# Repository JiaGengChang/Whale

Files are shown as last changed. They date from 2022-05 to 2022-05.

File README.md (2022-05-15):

# Whale Pro Micro

**Whale** is drop-in USB-C replacement for the sparkfun Pro Micro popular in split keyboards. It is a modified version of **[Goldfish]** by staticintlucas that uses a cheaply available USB-C receptacle. In Mandarin, goldfish sounds the same as whale.

Link to [Schematics]
Link to [PCB gerber files]

---

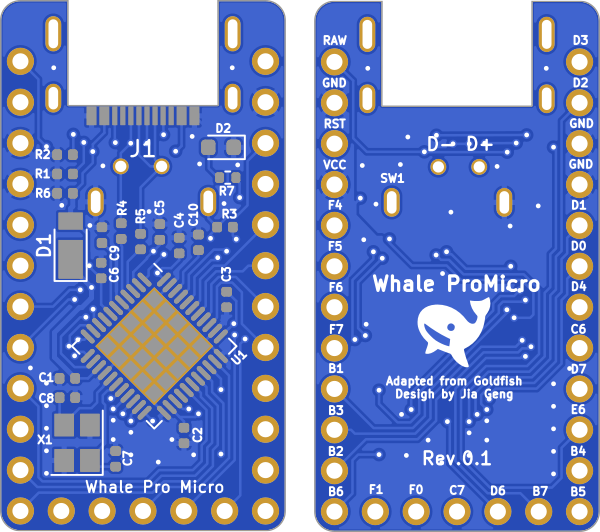
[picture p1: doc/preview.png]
Preview


---

## Modifications to Goldfish

- PCB designed to fit cheap USB-C connector available on aliexpress **[usb-c-link]**.
- Reset switch that can be soldered on the back of the board (6mm by 2.5mm switch)**[switch-link]**.
- Different silkscreen text and art
- LED for power-source
---

## Disadvantages compared to other Goldfish-based boards

- Unlike **[Alvaro]**, it does not incorporate a fuse
- It also uses 0402 form factor capacitors and resistors, which is difficult to solder by hand
- No working boards tested!! (verdict will be out soon, watch this space)
---

## License

**[Creative Commons Attribution Share-Alike 4.0 License][License]**.

**-** Original `Arduino Mini` design by **Team Arduino**.

**-** Arduino `Pro Mini` design by **Spark Fun Electronics**.

**-** `Pro Micro` design by **Spark Fun Electronics**.

**-** Wiring schematics largely based on Goldfish by Dr Derivative.

---

<!----------------------------------------------------------------------------->

[Goldfish]: https://github.com/staticintlucas/Goldfish
[Schematics]: doc/whale.pdf
[PCB gerber files]: cad/gerbers/
[Preview]: doc/preview.png
[usb-c-link]: https://www.aliexpress.com/item/32998900371.html?spm=a2g0o.order_list.0.0.31b61802zlAvym
[switch-link]: https://www.aliexpress.com/item/1005002490728099.html?spm=a2g0o.order_list.0.0.4c182faewbHx
[Alvaro]: https://github.com/Ariamelon/Alvaro
[License]: https://creativecommons.org/licenses/by-sa/4.0/

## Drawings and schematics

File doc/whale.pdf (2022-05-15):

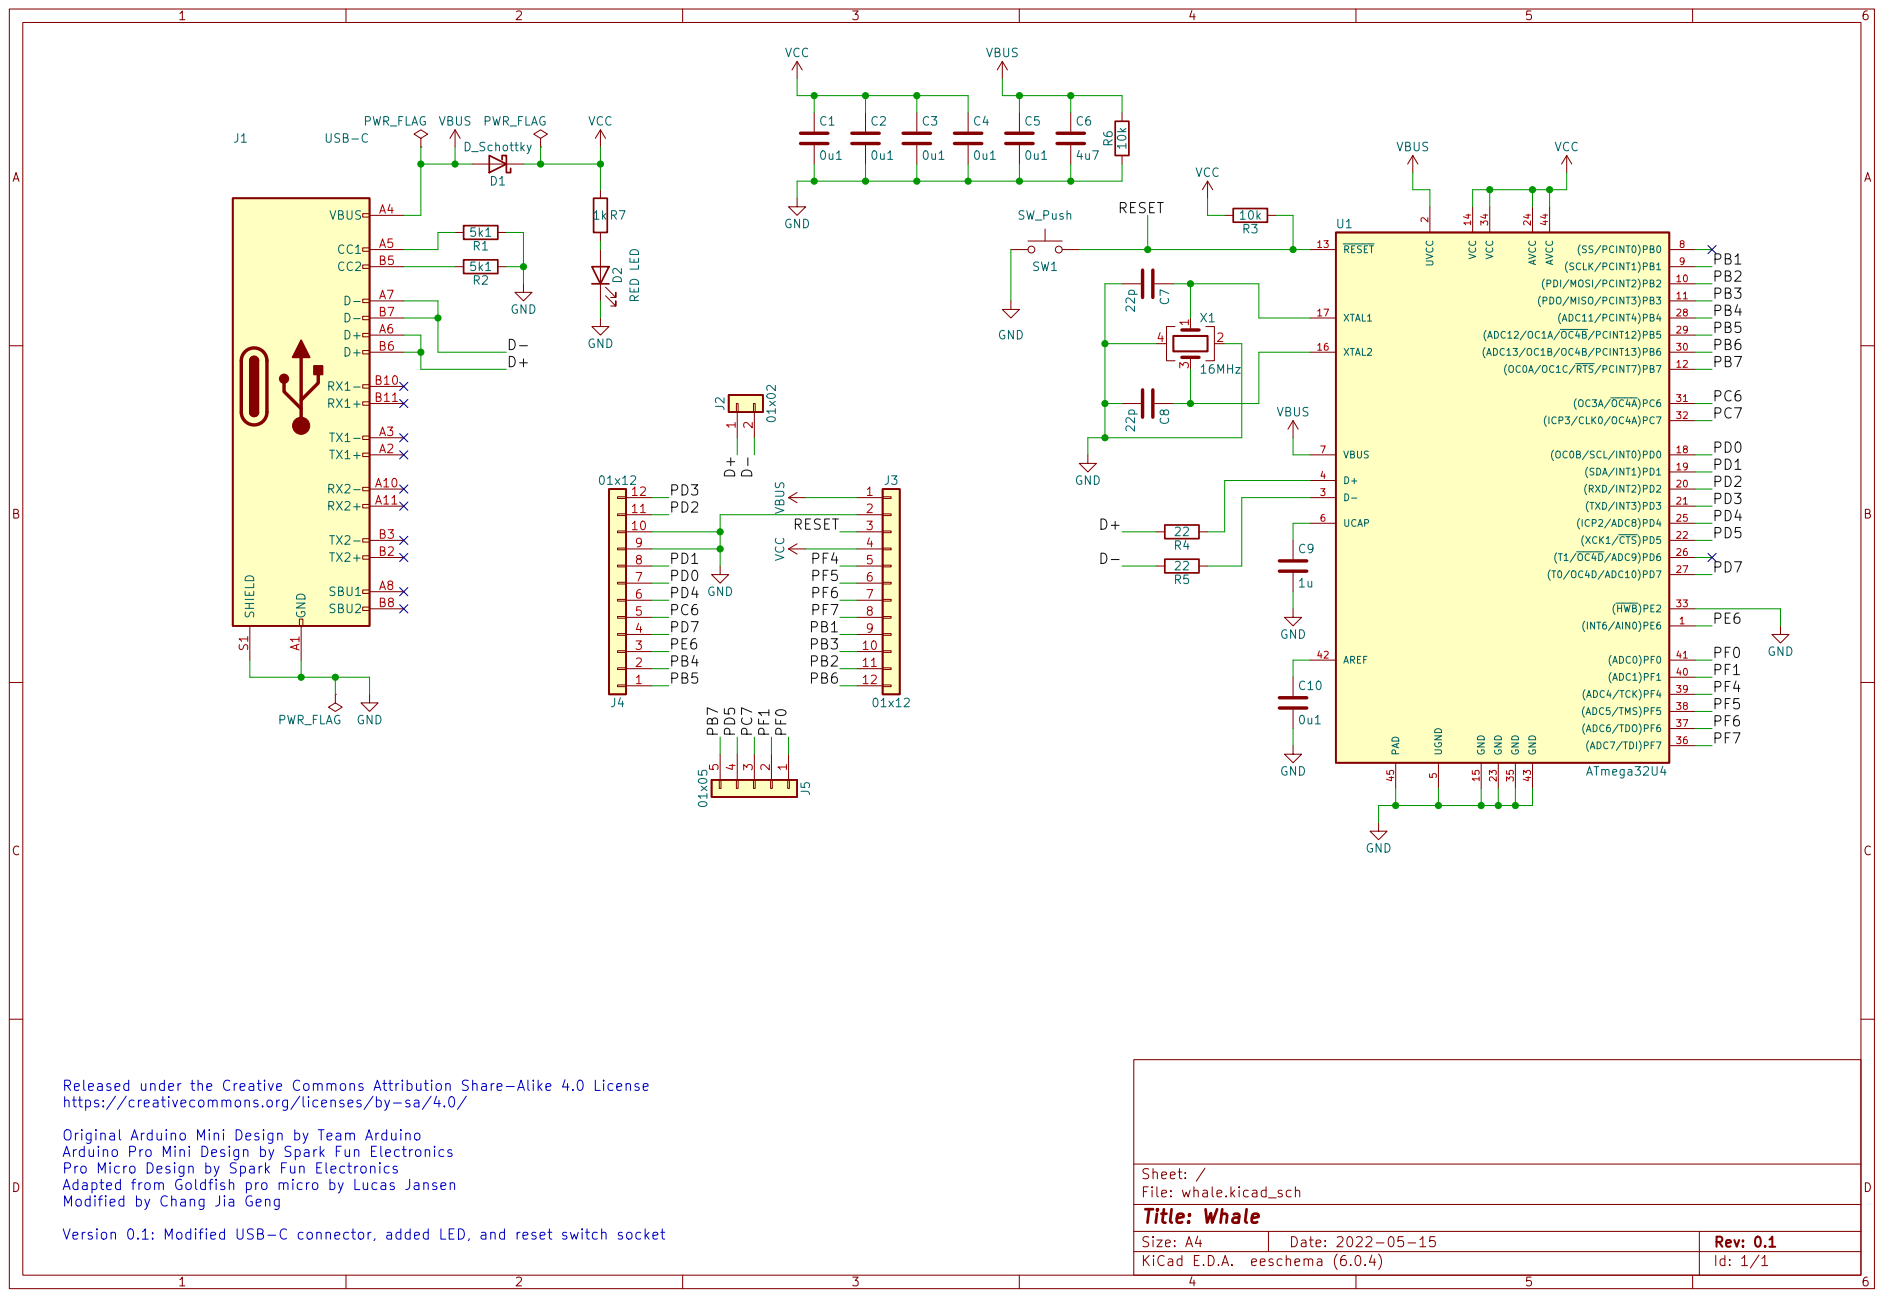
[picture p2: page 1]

PC7 PD0 Released under the Creative Commons Attribution Share-Alike 4.0 License

https://creativecommons.org/licenses/by-sa/4.0/

Original Arduino Mini Design by Team Arduino
Arduino Pro Mini Design by Spark Fun Electronics
Pro Micro Design by Spark Fun Electronics
Adapted from Goldfish pro micro by Lucas Jansen
Modified by Chang Jia Geng

Version 0.1: Modified USB-C connector, added LED, and reset switch socket

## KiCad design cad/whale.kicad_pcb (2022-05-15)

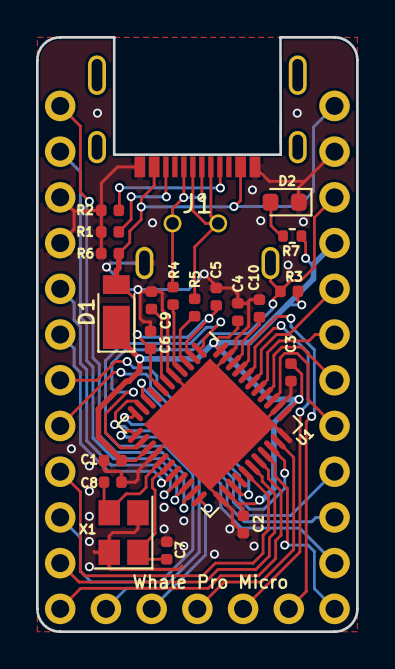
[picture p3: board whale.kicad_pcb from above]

Board: 2 copper layers, 17.8 x 33.0 mm, 27 parts (0 on the bottom side), 38 nets.

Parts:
C1, C2, C3, C4, C5, C10: 0u1; C_0402_1005Metric
C6: 4u7; C_0402_1005Metric
C7, C8: 22p; C_0402_1005Metric
C9: 1u; C_0402_1005Metric
D1: D_Schottky; D_PowerDI-123
D2: LED_0603_1608Metric
J1: USB-C; 16p-mid-mount-1.6mm
J2: 01x02; Pins2
J3, J4: 01x12; Pins12
J5: 01x05; Pins5
R1, R2: 5k1; R_0402_1005Metric
R3, R6: 10k; R_0402_1005Metric
R4, R5: 22; R_0402_1005Metric
R7: R_0402_1005Metric
U1: ATmega32U4; QFN-44-1EP_7x7mm_P0.5mm_EP5.2x5.2mm
Whale ProMicro: LOGO; logo
X1: 16MHz; Crystal_SMD_SeikoEpson_FA238-4Pin_3.2x2.5mm

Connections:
/D+: J1.A6, J1.B6, J2.1, R4.2
/D-: J1.A7, J1.B7, J2.2, R5.2
/PB1: J3.9, U1.9
/PB2: J3.11, U1.10
/PB3: J3.10, U1.11
/PB4: J4.2, U1.28
/PB5: J4.1, U1.29
/PB6: J3.12, U1.30
/PB7: J5.5, U1.12
/PC6: J4.5, U1.31
/PC7: J5.3, U1.32
/PD0: J4.7, U1.18
/PD1: J4.8, U1.19
/PD2: J4.11, U1.20
/PD3: J4.12, U1.21
/PD4: J4.6, U1.25
/PD5: J5.4, U1.22
/PD7: J4.4, U1.27
/PE6: J4.3, U1.1
/PF0: J5.1, U1.41
/PF1: J5.2, U1.40
/PF4: J3.5, U1.39
/PF5: J3.6, U1.38
/PF6: J3.7, U1.37
/PF7: J3.8, U1.36
/RESET: J3.3, R3.1, U1.13
CC1: J1.A5, R2.2
CC2: J1.B5, R1.2
GND: C1.2, C2.2, C3.2, C4.2, C5.2, C6.2, C7.2, C8.2, C9.2, C10.2, D2.1, J1.A1, J3.2, J4.9, J4.10, R1.1, R2.1, R6.1, U1.5, U1.15, U1.23, U1.33, U1.35, U1.43, U1.45, X1.2, X1.4
LED: D2.2, R7.2
unnamed: C7.1, U1.17, X1.1
unnamed: C8.1, U1.16, X1.3
unnamed: C9.1, U1.6
unnamed: C10.1, U1.42
unnamed: R4.1, U1.4
unnamed: R5.1, U1.3
VBUS: C5.1, C6.1, D1.2, J1.A4, J3.1, R6.2, U1.2, U1.7
VCC: C1.1, C2.1, C3.1, C4.1, D1.1, J3.4, R3.2, R7.1, U1.14, U1.24, U1.34, U1.44
